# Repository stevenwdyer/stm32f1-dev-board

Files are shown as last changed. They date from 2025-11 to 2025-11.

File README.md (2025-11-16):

# stm32f1-dev-board

This board is an STM32F103-based development platform, designed for prototyping and developing embedded applications. The design includes:

* An STM32F103C8T6 microcontroller, which features an ARM Cortex-M3 core and 128kB of flash.

* Support for multiple communication protocols, including CANbus, LINbus, I<sup>2</sup>C, SPI, USB, and UART.

* Dual clock sources, featuring a 32.768kHz crystal for precise RTC functionality, as well as an 8MHz system clock.

* An SWD interface, enabling firmware flashing and in-circuit debugging using an external ST-LINK.

* A 5V to 3.3V linear regulator, providing power for the MCU and all onboard circuitry from the USB input.

* User interface, via a reset button and a power indicator LED.

* A standardized form factor, with a 19x50mm footprint and 2.54mm pitch headers, enabling compatibility with standard breadboards for rapid prototyping.

### Images ###

Disk Sanitization Steps
Disk Sanitization Steps
Disk Sanitization Steps
Disk Sanitization Steps
Disk Sanitization Steps

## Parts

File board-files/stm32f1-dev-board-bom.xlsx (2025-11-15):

Comment | Designator | Footprint | JLCPCB Part #（optional）
100n | C1,C2,C3,C4,C6,C8 | Capacitor_SMD:C_0402_1005Metric | https://mm.digikey.com/Volume0/opasdata/d220001/medias/docus/609/CL05B104KP5NNNC_Spec.pdf
1u | C5,C7,C14 | Capacitor_SMD:C_0402_1005Metric | https://mm.digikey.com/Volume0/opasdata/d220001/medias/docus/3584/CL10B105KP8NNNC_Spec.pdf
20p | C9,C10 | Capacitor_SMD:C_0402_1005Metric | https://search.murata.co.jp/Ceramy/image/img/A01X/G101/ENG/GJM1555C1H200FB01-01.pdf
10p | C11,C12 | Capacitor_SMD:C_0402_1005Metric | https://mm.digikey.com/Volume0/opasdata/d220001/medias/docus/412/GRM1555C1H100FA01.pdf
22u | C13 | Capacitor_SMD:C_0805_2012Metric | https://mm.digikey.com/Volume0/opasdata/d220001/medias/docus/658/CL31A226KAHNNNE_Spec.pdf
RED | D1 | LED_SMD:LED_0201_0603Metric | https://www.we-online.com/components/products/datasheet/15406085BA300.pdf
USB_C_Receptacle_USB2.0_16P | J1 | Connector_USB:USB_C_Receptacle_GCT_USB4105-xx-A_16P_TopMnt_Horizontal | https://www.usb.org/sites/default/files/documents/usb_type-c.zip
Conn_01x04_Pin | J2 | Connector_PinHeader_2.54mm:PinHeader_1x04_P2.54mm_Vertical | https://www.we-online.com/components/products/datasheet/61300411121.pdf
Conn_01x19_Pin | J3,J4 | Connector_PinHeader_2.54mm:PinHeader_1x19_P2.54mm_Vertical | https://app.adam-tech.com/products/download/data_sheet/201605/ph1-xx-ua-data-sheet.pdf
390 | R1 | Resistor_SMD:R_0402_1005Metric | https://www.yageo.com/upload/media/product/products/datasheet/rchip/PYu-RC_Group_51_RoHS_L_12.pdf
5k1 | R2,R3 | Resistor_SMD:R_0402_1005Metric | https://www.digikey.ca/en/products/detail/yageo/RC0402FR-075KL/5917711
1k5 | R4,R5 | Resistor_SMD:R_0402_1005Metric | https://www.yageo.com/upload/media/product/products/datasheet/rchip/PYu-RC_Group_51_RoHS_L_12.pdf
SW_Push | SW1 | Button_Switch_SMD:SW_SPST_PTS810 | https://www.ckswitches.com/media/1476/pts810.pdf
STM32F103C8T6 | U1 | Package_QFP:LQFP-48_7x7mm_P0.5mm | https://www.st.com/resource/en/datasheet/stm32f103c8.pdf
USBLC6-2SC6 | U2 | Package_TO_SOT_SMD:SOT-23-6 | https://www.st.com/resource/en/datasheet/usblc6-2.pdf
AMS1117-3.3 | U3 | Package_TO_SOT_SMD:SOT-223-3_TabPin2 | http://www.advanced-monolithic.com/pdf/ds1117.pdf
8M | Y1 | Crystal:Crystal_SMD_3215-2Pin_3.2x2.5mm | https://www.waldom.com/upload/parts/datasheets/mf-abr/abr-ase-8000mhz-lc-t.pdf
32k768 | Y2 | Crystal:Crystal_SMD_2012-2Pin_3.2x2.5mm | https://abracon.com/Resonators/ABS06.pdf

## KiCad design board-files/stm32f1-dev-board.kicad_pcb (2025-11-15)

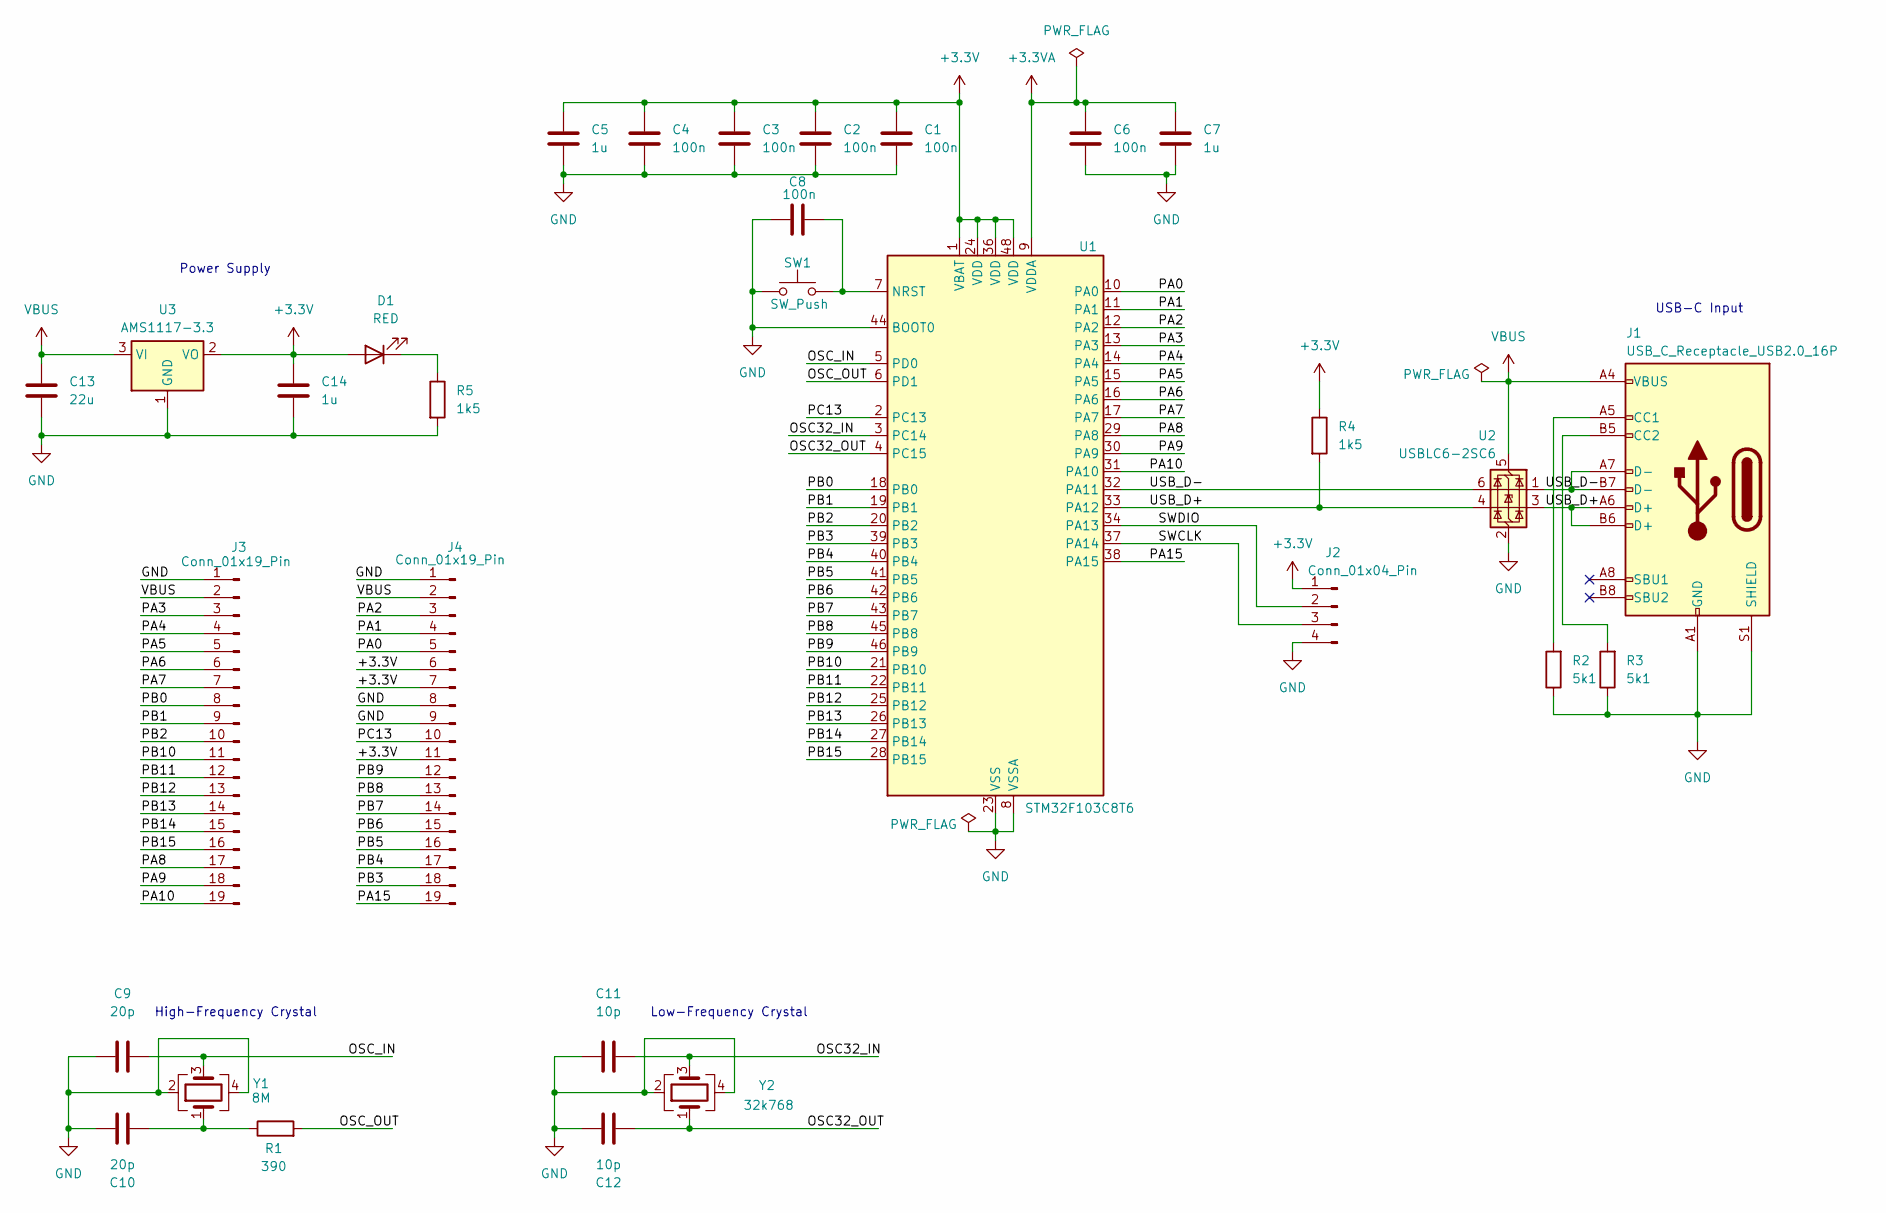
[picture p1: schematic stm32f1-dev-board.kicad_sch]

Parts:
C1, C2, C3, C4, C6, C8: 100n; C_0402_1005Metric
C5, C7, C14: 1u; C_0402_1005Metric
C9, C10: 20p; C_0402_1005Metric
C11, C12: 10p; C_0402_1005Metric
C13: 22u; C_0805_2012Metric
D1: RED; LED_0201_0603Metric
J1: USB_C_Receptacle_USB2.0_16P; USB_C_Receptacle_GCT_USB4105-xx-A_16P_TopMnt_Horizontal
J2: Conn_01x04_Pin; PinHeader_1x04_P2.54mm_Vertical
J3, J4: Conn_01x19_Pin; PinHeader_1x19_P2.54mm_Vertical
R1: 390; R_0402_1005Metric
R2, R3: 5k1; R_0402_1005Metric
R4, R5: 1k5; R_0402_1005Metric
SW1: SW_Push; SW_SPST_PTS810
U1: STM32F103C8T6; LQFP-48_7x7mm_P0.5mm
U2: USBLC6-2SC6; SOT-23-6
U3: AMS1117-3.3; SOT-223-3_TabPin2
Y1: 8M; Crystal_SMD_3225-4Pin_3.2x2.5mm
Y2: 32k768; Crystal_SMD_3225-4Pin_3.2x2.5mm

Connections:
+3.3V: C1.1, C2.1, C3.1, C4.1, C5.1, C14.1, D1.2 (A), J2.1, J4.6, J4.7, J4.11, R4.1, U1.1 (VBAT), U1.24 (VDD), U1.36 (VDD), U1.48 (VDD), U3.2 (VO)
+3.3VA: C6.1, C7.1, U1.9 (VDDA)
/OSC32_IN: C11.2, U1.3 (PC14), Y2.3
/OSC32_OUT: C12.2, U1.4 (PC15), Y2.1
/OSC_IN: C9.2, U1.5 (PD0), Y1.3
/OSC_OUT: R1.2, U1.6 (PD1)
/PA0: J4.5, U1.10 (PA0)
/PA1: J4.4, U1.11 (PA1)
/PA2: J4.3, U1.12 (PA2)
/PA3: J3.3, U1.13 (PA3)
/PA4: J3.4, U1.14 (PA4)
/PA5: J3.5, U1.15 (PA5)
/PA6: J3.6, U1.16 (PA6)
/PA7: J3.7, U1.17 (PA7)
/PA8: J3.17, U1.29 (PA8)
/PA9: J3.18, U1.30 (PA9)
/PA10: J3.19, U1.31 (PA10)
/PA15: J4.19, U1.38 (PA15)
/PB0: J3.8, U1.18 (PB0)
/PB1: J3.9, U1.19 (PB1)
/PB2: J3.10, U1.20 (PB2)
/PB3: J4.18, U1.39 (PB3)
/PB4: J4.17, U1.40 (PB4)
/PB5: J4.16, U1.41 (PB5)
/PB6: J4.15, U1.42 (PB6)
/PB7: J4.14, U1.43 (PB7)
/PB8: J4.13, U1.45 (PB8)
/PB9: J4.12, U1.46 (PB9)
/PB10: J3.11, U1.21 (PB10)
/PB11: J3.12, U1.22 (PB11)
/PB12: J3.13, U1.25 (PB12)
/PB13: J3.14, U1.26 (PB13)
/PB14: J3.15, U1.27 (PB14)
/PB15: J3.16, U1.28 (PB15)
/PC13: J4.10, U1.2 (PC13)
/SWCLK: J2.3, U1.37 (PA14)
/SWDIO: J2.2, U1.34 (PA13)
/USB_D+: J1.A6 (D+), J1.B6 (D+), R4.2, U1.33 (PA12), U2.3 (I/O2), U2.4 (I/O2)
/USB_D-: J1.A7 (D-), J1.B7 (D-), U1.32 (PA11), U2.1 (I/O1), U2.6 (I/O1)
GND: C1.2, C2.2, C3.2, C4.2, C5.2, C6.2, C7.2, C8.1, C9.1, C10.1, C11.1, C12.1, C13.2, C14.2, J1.A1 (GND), J1.A12 (GND), J1.B1 (GND), J1.B12 (GND), J1.S1 (SHIELD), J2.4, J3.1, J4.1, J4.8, J4.9, R2.1, R3.1, R5.2, SW1.1, U1.8 (VSSA), U1.23 (VSS), U1.35 (VSS), U1.44 (BOOT0), U1.47 (VSS), U2.2 (GND), U3.1 (GND), Y1.2, Y1.4, Y2.2, Y2.4
unnamed: C10.2, R1.1, Y1.1
unnamed: D1.1 (K), R5.1
unnamed: J1.A5 (CC1), R2.2
unnamed: J1.B5 (CC2), R3.2
unnamed: C8.2, SW1.2, U1.7 (NRST)
VBUS: C13.1, J1.A4 (VBUS), J1.A9 (VBUS), J1.B4 (VBUS), J1.B9 (VBUS), J3.2, J4.2, U2.5 (VBUS), U3.3 (VI)

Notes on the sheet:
USB-C Input
Power Supply
High-Frequency Crystal
Low-Frequency Crystal

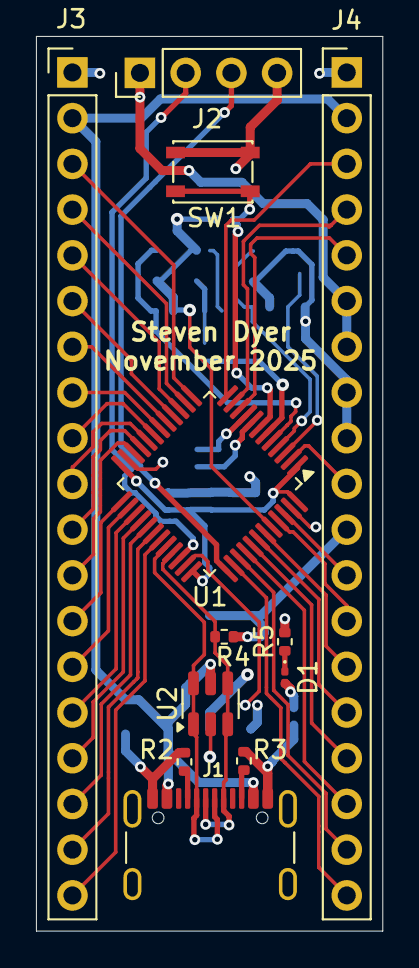
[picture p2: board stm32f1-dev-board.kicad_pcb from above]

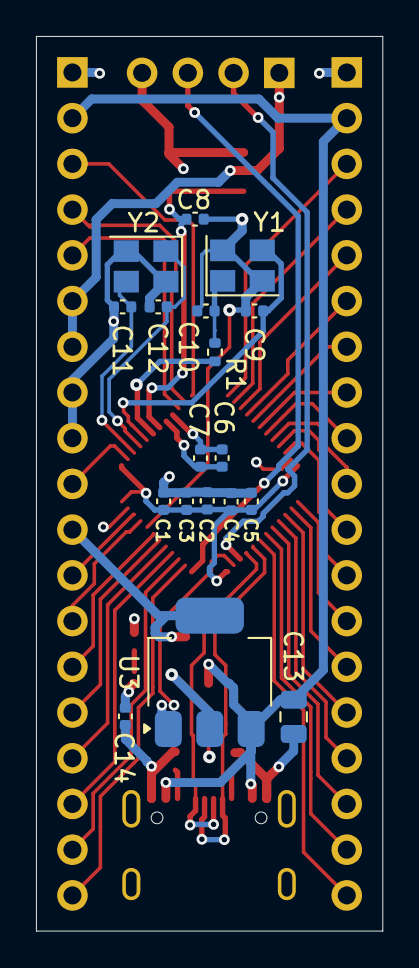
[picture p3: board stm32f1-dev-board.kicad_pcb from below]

Board: 4 copper layers, 19.2 x 49.7 mm, 30 parts (18 on the bottom side), 46 nets.

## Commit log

2025-11-15 Add board files
    [STM32_PCB_Test_Project-3_3V.gbr, STM32_PCB_Test_Project-B_Cu.gbr, STM32_PCB_Test_Project-B_Mask.gbr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]
2025-11-15 Update gerber files
    [stm32f1-dev-board-3_3V.gbr, stm32f1-dev-board-B_Cu.gbr, stm32f1-dev-board-B_Mask.gbr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]
